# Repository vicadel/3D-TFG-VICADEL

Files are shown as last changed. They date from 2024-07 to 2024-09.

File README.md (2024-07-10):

# 3D-TFG-VICADEL
# Final Degree Project - Vicadel

Hello! Welcome to the code repository and relevant information about Vicadel's Final Degree Project. Here you will find all the necessary code for the implementation and programming of the ESP32 board, which is essential for the operation of the 3D-printed arm prosthesis.

# This repository includes various files, such as:
- Initial code for testing the servomotors.
- Final code that integrates the operation through the Aoutecen EMG sensor.
- All the codes used for improvements and tests.

The objective is to provide a complete and detailed guide that facilitates the understanding and use of this project. I hope you enjoy the code and find all the information perfectly clear and useful for your needs.

# Repository Structure

- Initial Code: Files with basic examples for testing servomotors.
- Final Code: Optimized code ready for use with the Aoutecen EMG sensor.
- Improvements and Tests: Various files showing the iterations and improvements made during the project development.

## Usage Instructions

1. ESP32 Setup:
   - Download and install the Arduino software.
   - Configure the environment for the ESP32 and upload the corresponding code.

2. Connecting the EMG Sensors:
   - Connect the EMG sensors to the analog pins of the ESP32.
   - Ensure proper placement of the electrodes on the appropriate muscles.

3. Testing and Adjustments:
   - Perform initial tests to verify the prosthesis response.
   - Adjust the tension of the cables and the code parameters to improve the system's accuracy and response.

For more details, consult the attached files and documentation in this repository. If you have any questions or need additional assistance, you can contact me at vicadel@alumni.uv.es.

I hope you enjoy exploring and using this project as much as I enjoyed developing it!

---
Vicadel

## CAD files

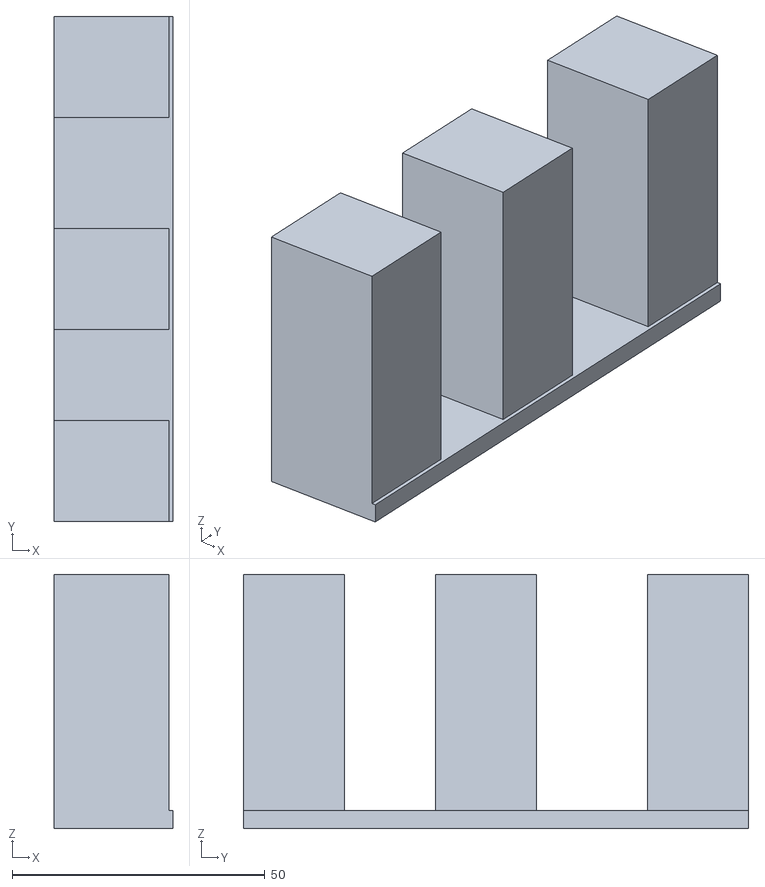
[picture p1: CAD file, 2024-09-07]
MODIFIED PARTS/BASE MANO-CREADA/Base-Mano-Creada.stl
23.5 x 100.0 x 50.3

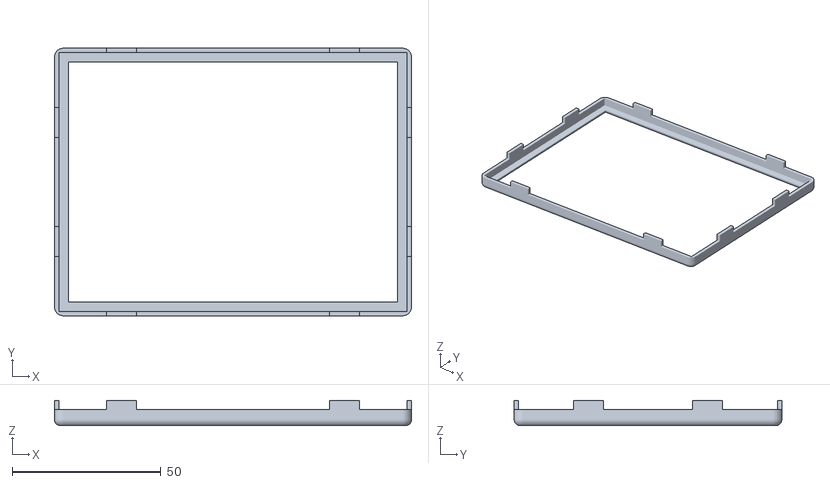
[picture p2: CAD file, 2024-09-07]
MODIFIED PARTS/CAMA ESP32-CREADA-MODIFICADA/ESP32-Soporte-Mod-Creado.stl
120.0 x 90.0 x 8.50

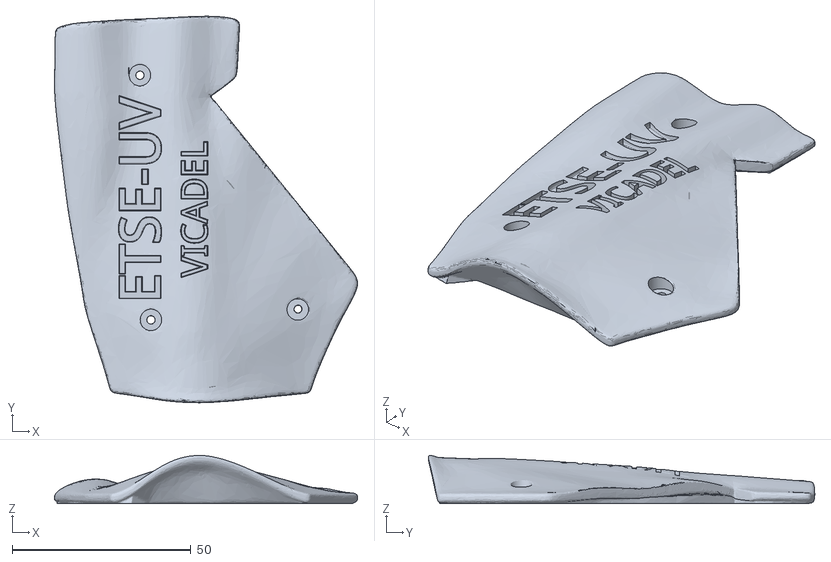
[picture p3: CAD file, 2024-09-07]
MODIFIED PARTS/MANO-CUBIERTA-MODIFICADA/MANO FINAL.stl
84.8 x 108.2 x 13.5

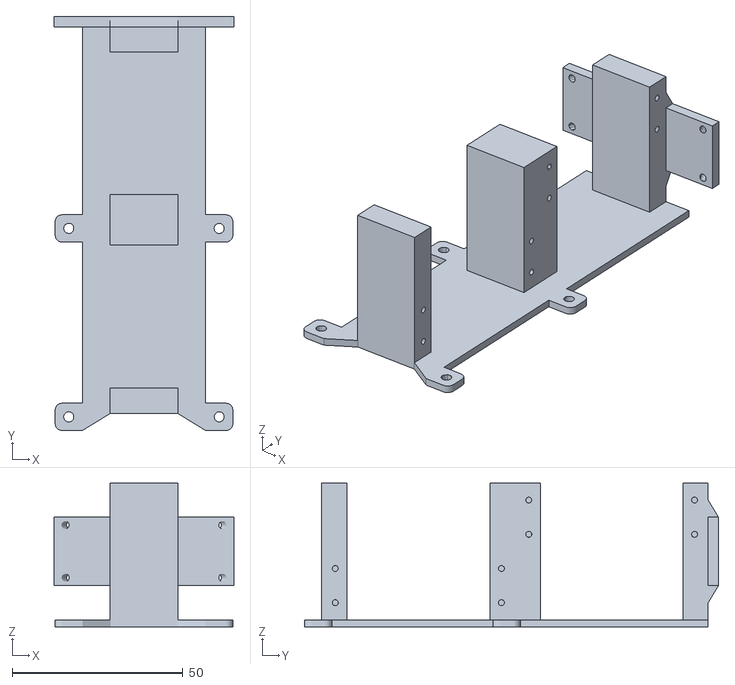
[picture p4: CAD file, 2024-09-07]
MODIFIED PARTS/SERVOBED-CREADA-MODIFICADA/Cama-Servo-modificada.stl
52.6 x 121.1 x 42.1

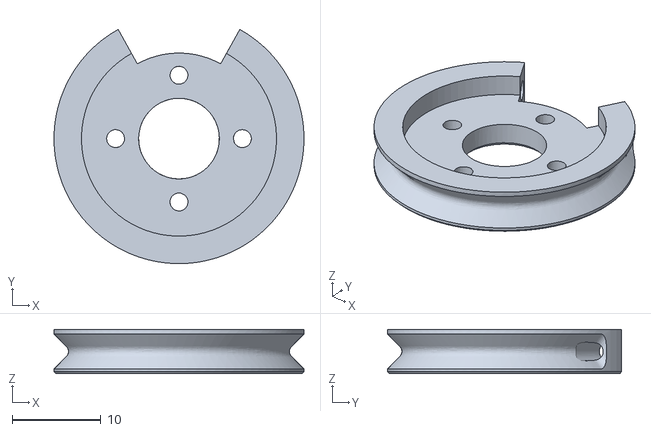
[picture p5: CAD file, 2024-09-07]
MODIFIED PARTS/SERVOPULLEY-MODIFICADA/Servo-pullet-modificado.stl
28.2 x 26.4 x 5.00

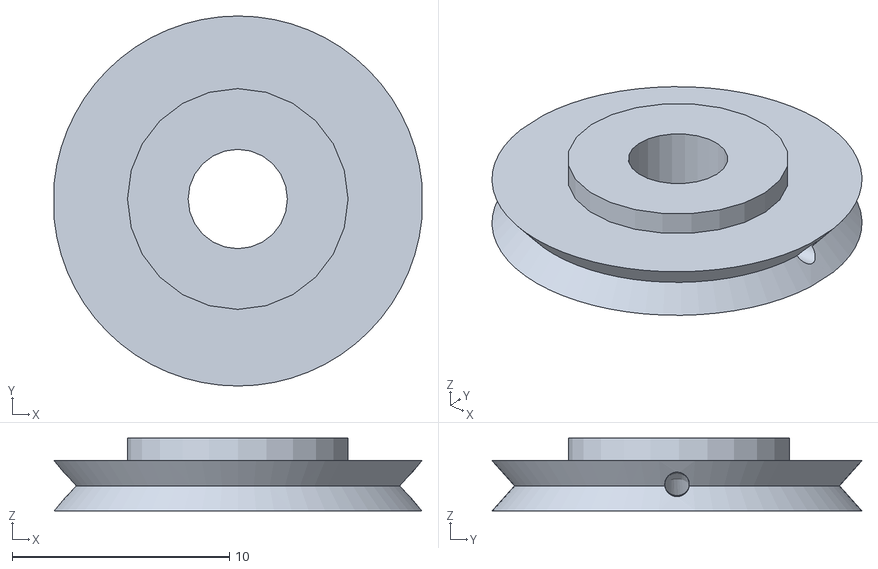
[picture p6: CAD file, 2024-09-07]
MODIFIED PARTS/SERVOROBRING MODIFICADA/Servo-RobRing-Modificada.stl
16.9 x 17.0 x 3.36

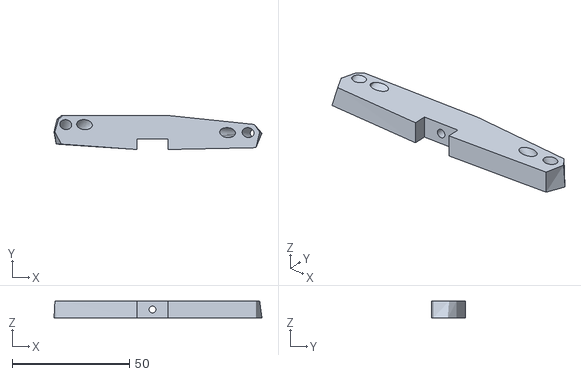
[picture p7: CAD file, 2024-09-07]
STLs/Forearm-servo-bed/RobCableBackV3.stl
88.7 x 14.5 x 7.17

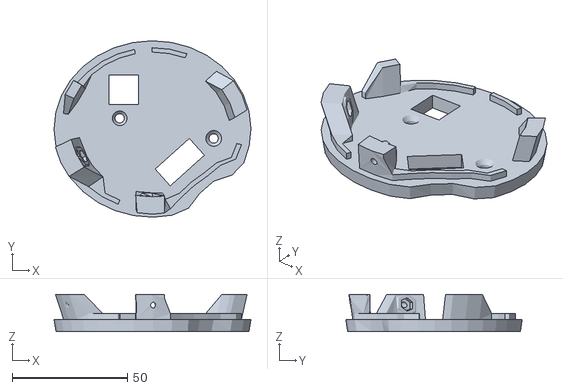
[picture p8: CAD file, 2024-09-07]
STLs/Right-Hand/robcap3V2.stl
85.5 x 76.5 x 16.2

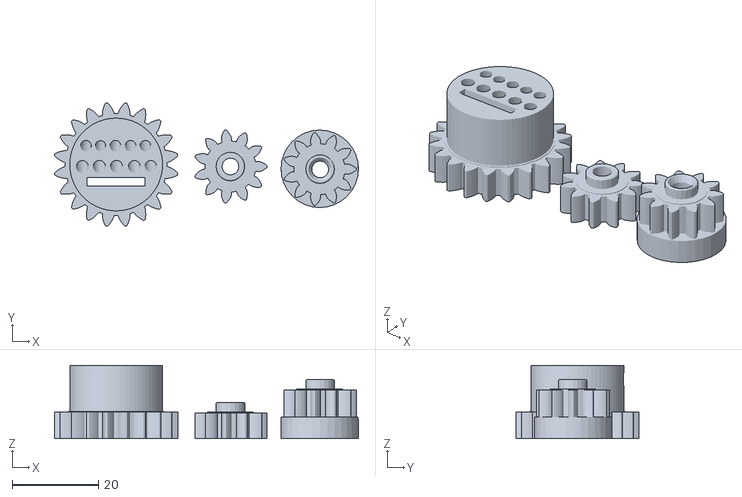
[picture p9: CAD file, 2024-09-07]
STLs/Rotation-Wrist/WristGearsV5.stl
70.7 x 28.7 x 17.1

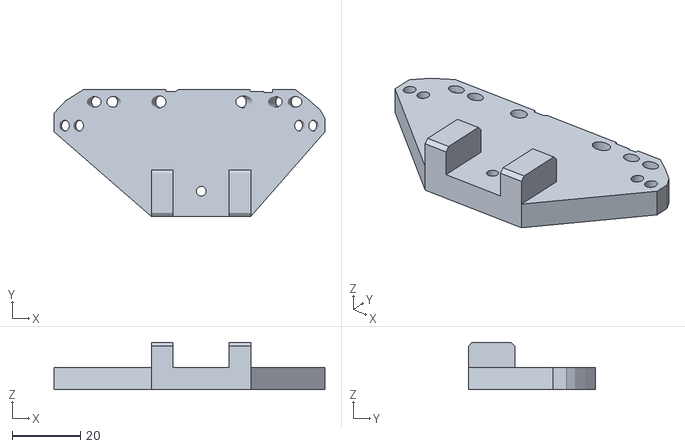
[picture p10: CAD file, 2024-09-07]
STLs/Forearm-servo-bed/RobCableFrontV3.stl
79.3 x 37.1 x 13.8

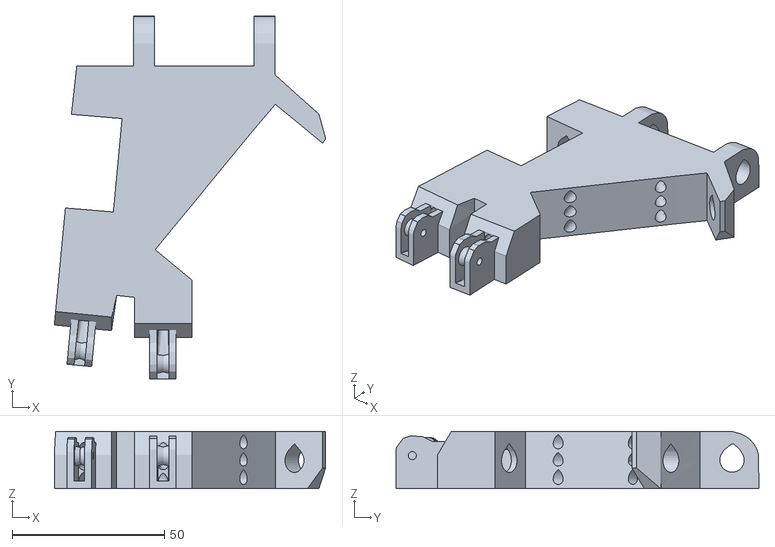
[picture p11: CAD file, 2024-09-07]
STLs/Right-Hand/WristlargeV4.stl
89.2 x 119.4 x 18.9

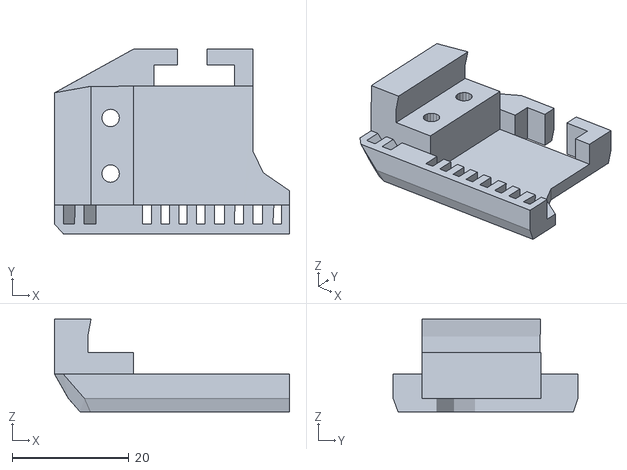
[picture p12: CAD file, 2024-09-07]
STLs/Rotation-Wrist/CableHolderWristV5.stl
40.2 x 31.6 x 15.8

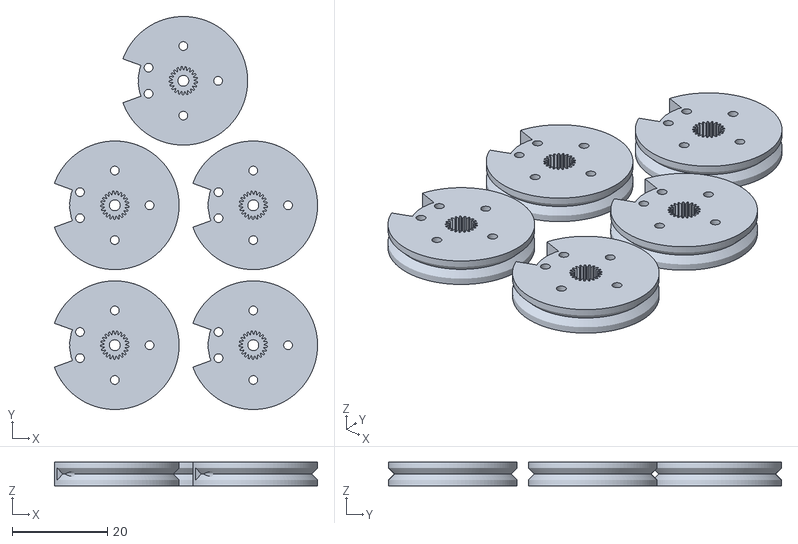
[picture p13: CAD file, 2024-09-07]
STLs/Forearm-servo-bed/RobRingV3.stl
55.3 x 82.5 x 5.00

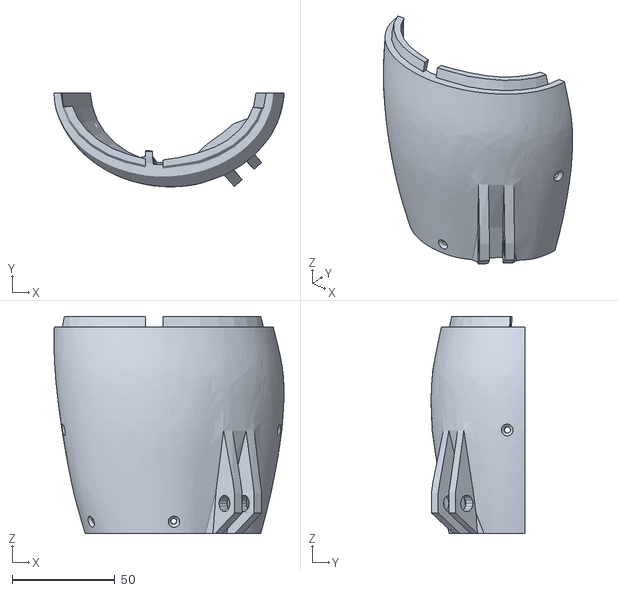
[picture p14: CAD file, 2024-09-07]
STLs/Right-Hand/robpart4V4.stl
111.8 x 45.5 x 105.6

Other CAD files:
STLs/Rotation-Wrist/RotaWrist2V3.stl
STLs/Forearm-servo-bed/RobServoBedV6.stl
STLs/Right-Hand/coverfinger1.stl
STLs/Rotation-Wrist/RotaWrist3V3.stl
STLs/Forearm-servo-bed/TensionerRightV1.stl
STLs/Forearm-servo-bed/servo-pulleyX5.stl
STLs/Right-Hand/Auriculaire3.stl
STLs/Right-Hand/Bolt_entretoise7.stl
STLs/Right-Hand/ESP32support.stl
STLs/Right-Hand/FINAL-TOPSURFACE.stl
STLs/Right-Hand/Index3.stl
STLs/Right-Hand/Majeure3.stl
STLs/Right-Hand/WristsmallV4.stl
STLs/Right-Hand/robpart2V4.stl
STLs/Right-Hand/robpart3V4.stl
STLs/Right-Hand/robpart5V4.stl
STLs/Right-Hand/thumb5.stl
STLs/Right-Hand/topsurface6.stl
STLs/Right-Hand/topsurfaceUP6.stl
STLs/Rotation-Wrist/RotaWrist1V4.stl

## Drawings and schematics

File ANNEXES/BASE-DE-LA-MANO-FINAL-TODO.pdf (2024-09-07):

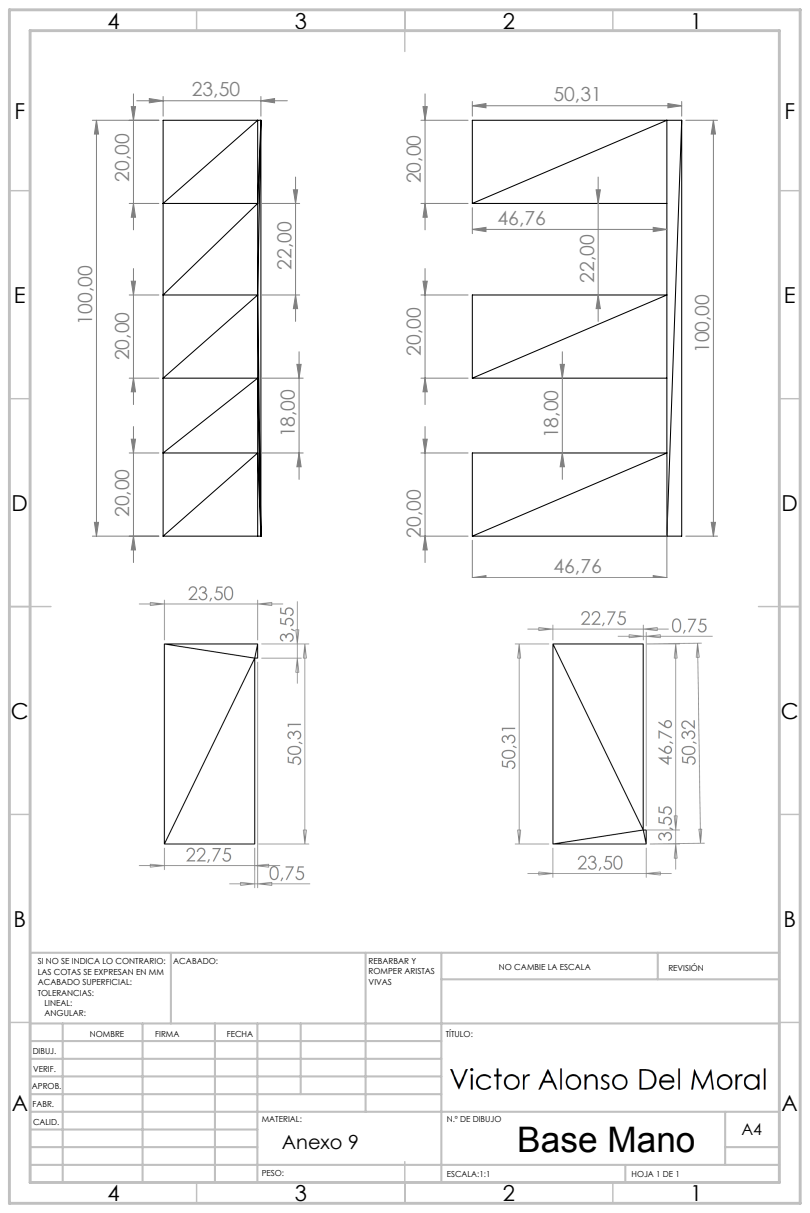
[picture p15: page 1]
ACABADO:; REBARBAR Y; ROMPER ARISTAS; NO CAMBIE LA ESCALA; REVISIÓN; ESCALA:1:1; HOJA 1 DE 1

SI NO SE INDICA LO CONTRARIO:
LAS COTAS SE EXPRESAN EN MM
ACABADO SUPERFICIAL:
TOLERANCIAS:
LINEAL:
ANGULAR:

Victor Alonso Del Moral

NOMBRE | FIRMA | FECHA | | | | TÍTULO: Base de la Mano

DIBUJ.
VERIF.
APROB.
FABR.
CALID. | | | | MATERIAL: Anexo 9 | N.º DE DIBUJO Base Mano | A4

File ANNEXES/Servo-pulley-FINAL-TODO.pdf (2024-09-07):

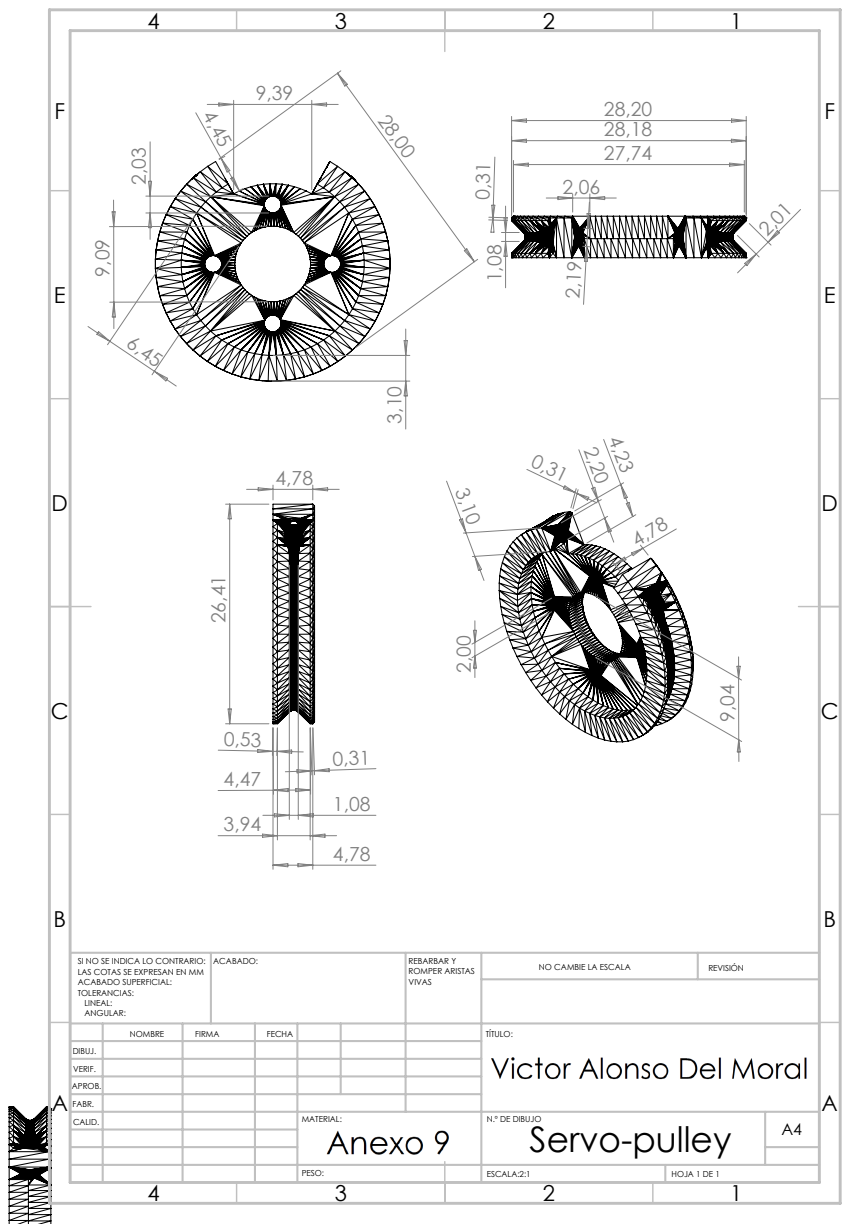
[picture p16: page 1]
ACABADO:; REBARBAR Y; ROMPER ARISTAS; NO CAMBIE LA ESCALA; REVISIÓN; ESCALA:2:1; HOJA 1 DE 1

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

NOMBRE | FIRMA | FECHA | | | | TÍTULO:

DIBUJ.
VERIF.
APROB.
FABR.
CALID. | | | | MATERIAL: | N.º DE DIBUJO Servo-pulley | A4

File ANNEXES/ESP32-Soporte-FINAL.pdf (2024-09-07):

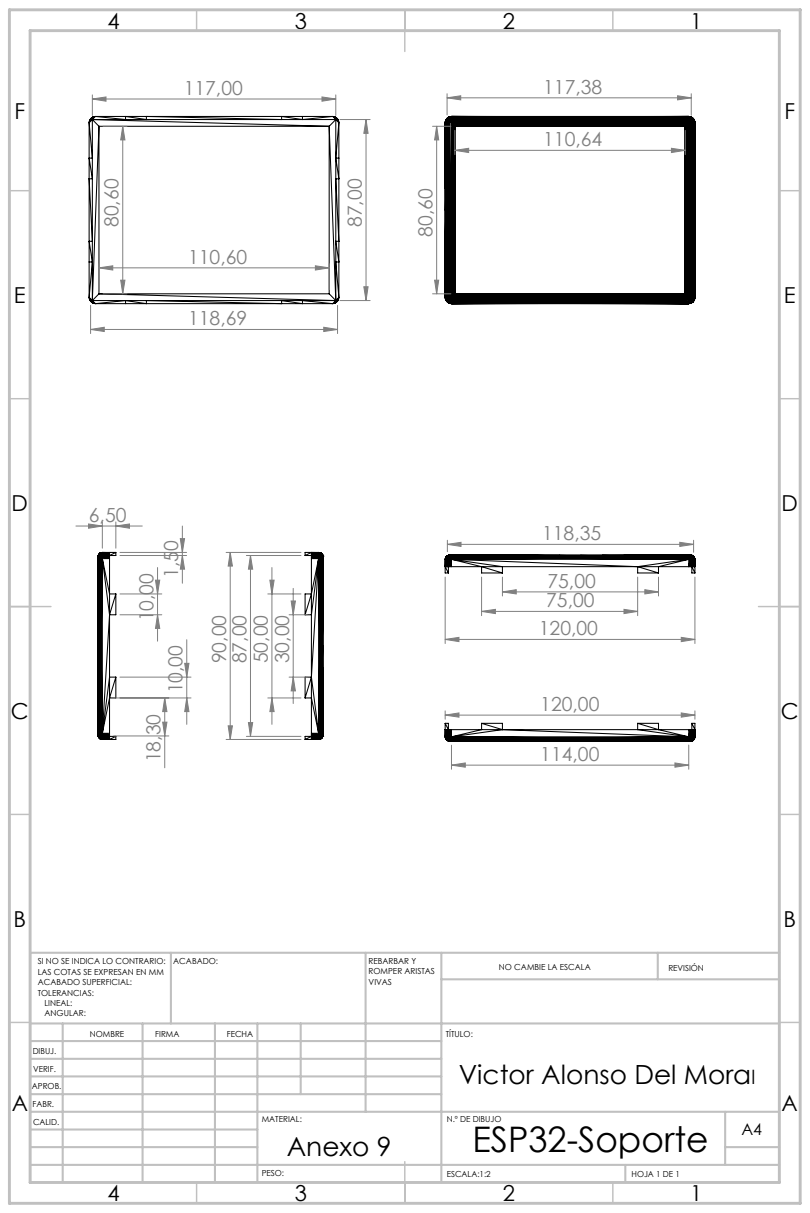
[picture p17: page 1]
ACABADO:; REBARBAR Y; ROMPER ARISTAS; NO CAMBIE LA ESCALA; REVISIÓN; ESCALA:1:2; HOJA 1 DE 1

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

NOMBRE | FIRMA | FECHA | | | | TÍTULO: Victor Alonso Del Moral

DIBUJ.
VERIF.
APROB.
FABR.
CALID. | | | | MATERIAL: Anexo 9 | N.º DE DIBUJO ESP32-Soporte | A4

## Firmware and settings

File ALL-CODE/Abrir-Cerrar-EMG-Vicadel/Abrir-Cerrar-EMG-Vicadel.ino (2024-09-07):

//Script to control InMoov Arm using Aoutecen EMG Muscle Sensor V3 from Advancer Technologies
//by Victor Alonso (vicadel@alumni.uv.es)
//Valencia (Spain)
//July 2024
//Part of TFG 3D Prostetic Hand & Forarm - InMoov Project 

//For information about Aoutecen EMG Muscle Sensor V3 board, manual and other resources, please visit:
//https://www.tme.eu/Document/8732078ad54d82f6b49c5284341026b5/POLOLU-2726.pdf


/*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
 * You should have received a copy of the GNU General Public License
 * along with this program.  If not, see <http://www.gnu.org/licenses/>.
 * */


//Incluye la librería ESP32Servo que permite controlar servomotores con un ESP32
#include <ESP32Servo.h>
//ESP32 esta definido - flexibilidad y concrecion para el micro ESP32             
#ifdef ESP32    

// Definición de pines analógicos y digitales para el ESP32
//ANALOGICOS A0-A7
#define A0 2
#define A1 4
#define A2 35
#define A3 34
#define A4 36
#define A5 39
#define A6 32
#define A7 33
//DIGITALES D2-D13 
#define D2 26
#define D3 25
#define D4 17
#define D5 16
#define D6 27
#define D7 14
#define D8 12
#define D9 13
#define D10 5
#define D11 23
#define D12 19
#define D13 18
#endif


//TENGO QUE CAMBIAR LOS PINES DE ARDUINO A ESP32 CON LA TABLA DE VICENT
#define THRESHOLD 14 //In order to determine the state of the hand (opened/closed)
#define EMGPIN     A2 //Analog pin connected to Muscle Sensor V3 Board
#define LITTLEPIN  D2 //Digital pin used by Little servo
#define RINGPIN    D3 //Digital pin used by Ring servo
#define MIDDLEPIN  D4 //Digital pin used by Middle servo
#define INDEXPIN   D5 //Digital pin used by Index servo
#define THUMBPIN  D6 //Digital pin used by Thumb servo

//Constants used to open and close the fingers
#define LITTLE 1 
#define RING   2
#define MIDDLE 3
#define INDEX  4
#define THUMB  5
//TENGO QUE CAMBIAR LOS PINES DE ARDUINO A ESP32 CON LA TABLA DE VICENT




Servo servoLittleFinger;         // Define servo fingers
Servo servoRingFinger;           // Define servo fingers
Servo servoMiddleFinger;         // Define servo fingers
Servo servoIndexFinger;          // Define servo fingers
Servo servoThumbFinger;          // Define servo fingers

int finger;

// Motion routines for handopen and handclose
void openhand(){for(finger = 1; finger < 6; finger++){openFinger(finger);}}
void closehand(){for(finger = 1; finger < 6 ; finger++){closeFinger(finger);}}

// You have to rewrite properly the functions to open and close the fingers 
// according of your assembly
// In my case, middle and index fingers are opened when servo is at 170 degrees and the others when servo is at 0 degrees
// I have used Towardpro MG996R servos

void openFinger(int finger){
  if(finger==LITTLE){servoLittleFinger.write(0);} // Little finger
  else if(finger==RING){servoRingFinger.write(180);}// Ring finger
  else if(finger==MIDDLE){servoMiddleFinger.write(180);}// Middle finger   //170
  else if(finger==INDEX){servoIndexFinger.write(180);}// Index finger
  else if(finger==THUMB){servoThumbFinger.write(0);}//Thumb finger
}

void closeFinger(int finger){
  if(finger==LITTLE){servoLittleFinger.write(180);} // Little finger 
  else if(finger==RING){servoRingFinger.write(0);}// Ring finger
  else if(finger==MIDDLE){servoMiddleFinger.write(0);}// Middle finger
  else if(finger==INDEX){servoIndexFinger.write(0);}// Index finger         
  else if(finger==THUMB){servoThumbFinger.write(180);}//Thumb finger        //170
}

void setup(){
  
  Serial.begin(9600); //BAUDRATE set to 115200, remember it to set monitor serial properly (used this BaudRate and "NL&CR" option to visualize the values correctly)

  //puerto serie me comunico a 9600 baudios mirar lectura, mirar paraemtros por defecto del programa, 

  servoLittleFinger.attach(LITTLEPIN);      // Set Little finger servo to digital pin 3
  servoRingFinger.attach(RINGPIN);          // Set Ring finger servo to digital pin 5
  servoMiddleFinger.attach(MIDDLEPIN);      // Set Middle finger servo to digital pin 6
  servoIndexFinger.attach(INDEXPIN);        // Set Index finger servo to digital pin 9
  servoThumbFinger.attach(THUMBPIN);        // Set Thumb finger servo to digital pin 10

}//end setup

void loop() {// Nothing to do here, all is done in the interrupt function

  int value = analogRead(EMGPIN); //Sampling analog signal
  if(value>THRESHOLD) //If the value of the sample is greater than THRESHOLD means that the hand has been closed
  {closehand();}
  else //Otherwise the hand is open
  {openhand();}
  Serial.println(value); //You can use serial monitor to set THRESHOLD properly, comparing the values shown when you open and close your hand
}

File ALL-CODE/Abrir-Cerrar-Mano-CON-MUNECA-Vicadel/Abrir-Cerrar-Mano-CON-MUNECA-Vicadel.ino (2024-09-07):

//Script to control InMoov Arm using Aoutecen EMG Muscle Sensor V3 from Advancer Technologies
//by Victor Alonso (vicadel@alumni.uv.es)
//Valencia (Spain)
//July 2024
//Part of TFG 3D Prosthetic Hand & Forearm - InMoov Project 

//For information about Aoutecen EMG Muscle Sensor V3 board, manual and other resources, please visit:
//https://www.tme.eu/Document/8732078ad54d82f6b49c5284341026b5/POLOLU-2726.pdf


/*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
 * You should have received a copy of the GNU General Public License
 * along with this program.  If not, see <http://www.gnu.org/licenses/>.
 * */

// Includes the ESP32Servo library which allows control of servomotors with an ESP32
#include <ESP32Servo.h>

// Check if ESP32 is defined - provides flexibility and specificity for the ESP32 microcontroller
#ifdef ESP32    

// Define analog and digital pins for the ESP32
// ANALOG PINS A0-A7
#define A0 2
#define A1 4
#define A2 35
#define A3 34
#define A4 36
#define A5 39
#define A6 32
#define A7 33

// DIGITAL PINS D2-D13 
#define D2 26
#define D3 25
#define D4 17
#define D5 16
#define D6 27
#define D7 14
#define D8 12
#define D9 13
#define D10 5
#define D11 23
#define D12 19
#define D13 18
#endif

// Define servo objects for fingers
// myservo1-5 are for the fingers
// myservo6 is for the wrist, commented out because for the first exercise
// we only want finger movement, not wrist movement

// int servo_pin = 9;  // for Arduino microcontroller
// int servo_pin = D7;  // for ESP8266 microcontroller
// int servo_pin = D2;  // for ESP32 microcontroller

// Initialization of servo objects
Servo myservo1, myservo2, myservo3, myservo4, myservo5, myservo6;

int angle = 0;  // Variable to store the angle of the servomotors 

void setup() 
{ 
  // Attach each servomotor to a digital pin on the ESP32
  myservo1.attach(D2);    // Attach the first servomotor to pin D2 (26)                   //MENIQUE
  myservo2.attach(D3);    // Attach the second servomotor to pin D3 (25)                  //ANULAR
  myservo3.attach(D4);    // Attach the third servomotor to pin D4 (17)                   //CORAZON
  myservo4.attach(D5);    // Attach the fourth servomotor to pin D5 (16)                  //INDICE
  myservo5.attach(D6);    // Attach the fifth servomotor to pin D6 (27)                   //PULGAR
  //myservo6.attach(D7);  // Attach the sixth servomotor to pin D7 (14), 
} 

void loop() 
{ 
  // Move from 0 to 180 degrees with a positive angle of 1
  for(angle = 0; angle < 180; angle += 1)
  {                          
    myservo1.write(180 - angle);  // Move the first servo to the position 180 - angle, a temporary adjustment to fix the servo's reverse direction
    myservo2.write(angle);        // Move the second servo to the position angle
    myservo3.write(angle);        // Move the third servo to the position angle
    myservo4.write(angle);        // Move the fourth servo to the position angle
    myservo5.write(angle);        // Move the fifth servo to the position angle
    //myservo6.write(angle);     // Move the sixth servo to the position angle (IN TESTING)
    delay(15);                    // Wait 15 milliseconds to smooth the servo's movement                
  } 

  delay(1000);                    // Wait 1 second before starting the next movement
  
  // Move from 180 to 0 degrees with a negative angle of 5
  for(angle = 180; angle >= 1; angle -= 5)
  {                                
    myservo1.write(180 - angle);  // Move the first servo to the position 180 - angle
    myservo2.write(angle);        // Move the second servo to the position angle
    myservo3.write(angle);        // Move the third servo to the position angle
    myservo4.write(angle);        // Move the fourth servo to the position angle
    myservo5.write(angle);        // Move the fifth servo to the position angle
    //myservo6.write(180 - angle);  // Move the sixth servo to the position 180 - angle (IN TESTING)
    delay(5);                     // Wait 5 milliseconds to smooth the servo's movement
  } 

  delay(1000);                    // Wait 1 second before repeating the cycle
}

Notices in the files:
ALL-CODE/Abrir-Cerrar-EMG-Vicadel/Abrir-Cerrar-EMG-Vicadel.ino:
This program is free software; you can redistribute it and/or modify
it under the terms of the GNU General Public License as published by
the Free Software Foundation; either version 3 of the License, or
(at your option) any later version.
